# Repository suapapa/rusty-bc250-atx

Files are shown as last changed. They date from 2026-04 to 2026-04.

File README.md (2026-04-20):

# Rusty BC250 ATX

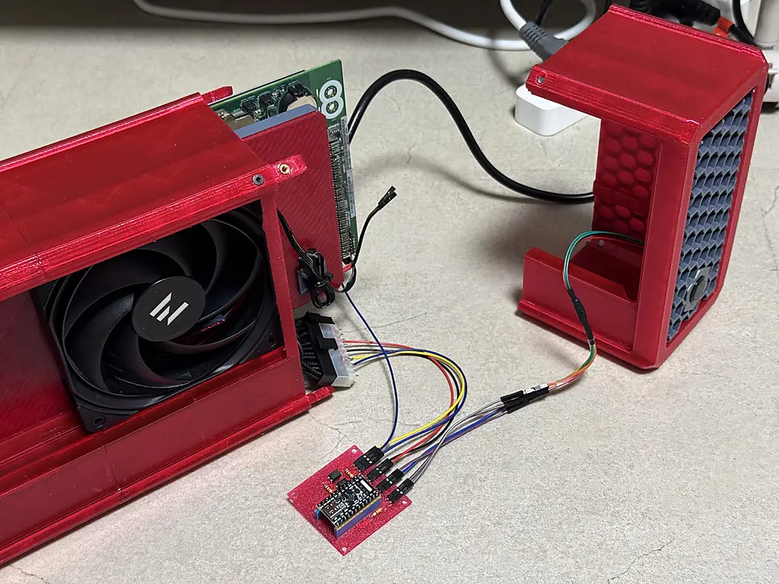
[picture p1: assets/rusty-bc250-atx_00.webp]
rusty-bc250-atx_00


- [In Action Video](https://www.youtube.com/watch?v=EkOmVfLqIu4)

ATX PSU soft-power adapter for the AMD BC250 mining board.
The BC250 lacks native ATX PS_ON circuitry; this firmware bridges that gap using a CH32V003 microcontroller.

## Features

| Function | Description |
|---|---|
| PS_ON control | Drive ATX PS_ON via optocoupler — active LOW at ATX connector, active HIGH at MCU |
| HOST_ON sense | Detect BC250 running state via optocoupler (12 V → 3.3 V isolated) |
| Power button | Debounced momentary button with short-press / long-press detection |
| Force off | 4-second hold → hard-cut ATX PS_ON regardless of HOST_ON state |
| LED output | Power status indicator (15 mA limited; J1 bypass up to 250 mA) |

## Board Assembly

The prototype PCB shown below was manufactured using a 3D printer.
- [sch/](sch/rusty-bc250-atx/) — KiCad schematic and PCB design
- [pcb_3dprint/](pcb_3dprint/) — STL and OpenSCAD files for 3D-printed PCB prototyping

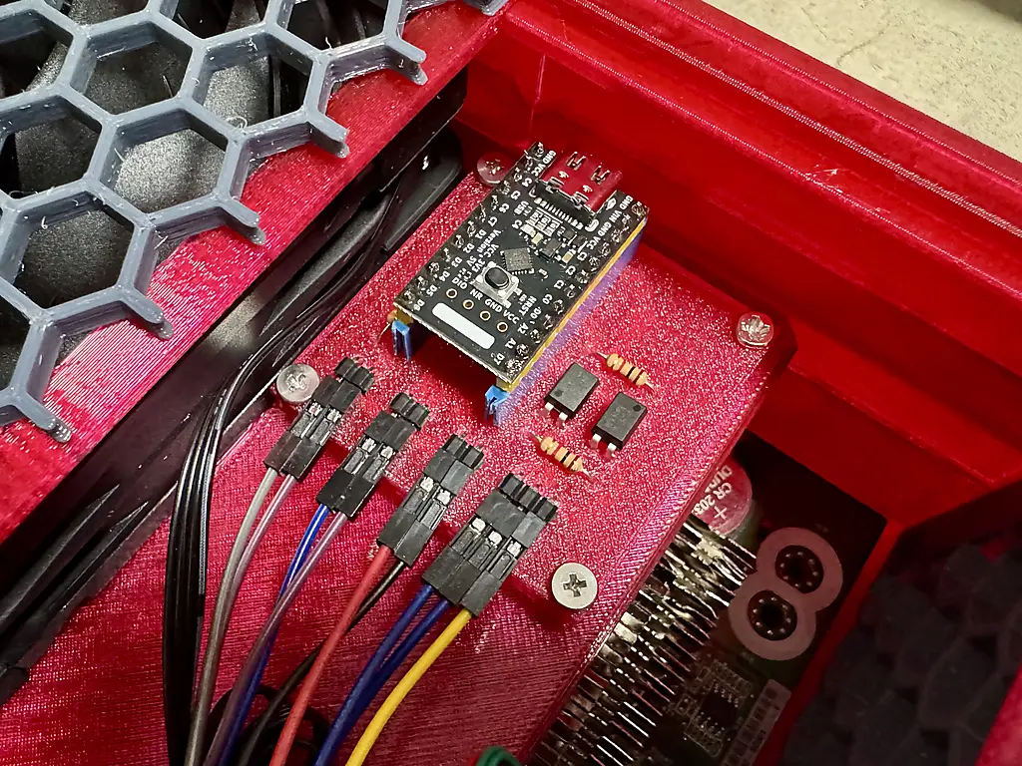
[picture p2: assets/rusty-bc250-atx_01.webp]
rusty-bc250-atx_01

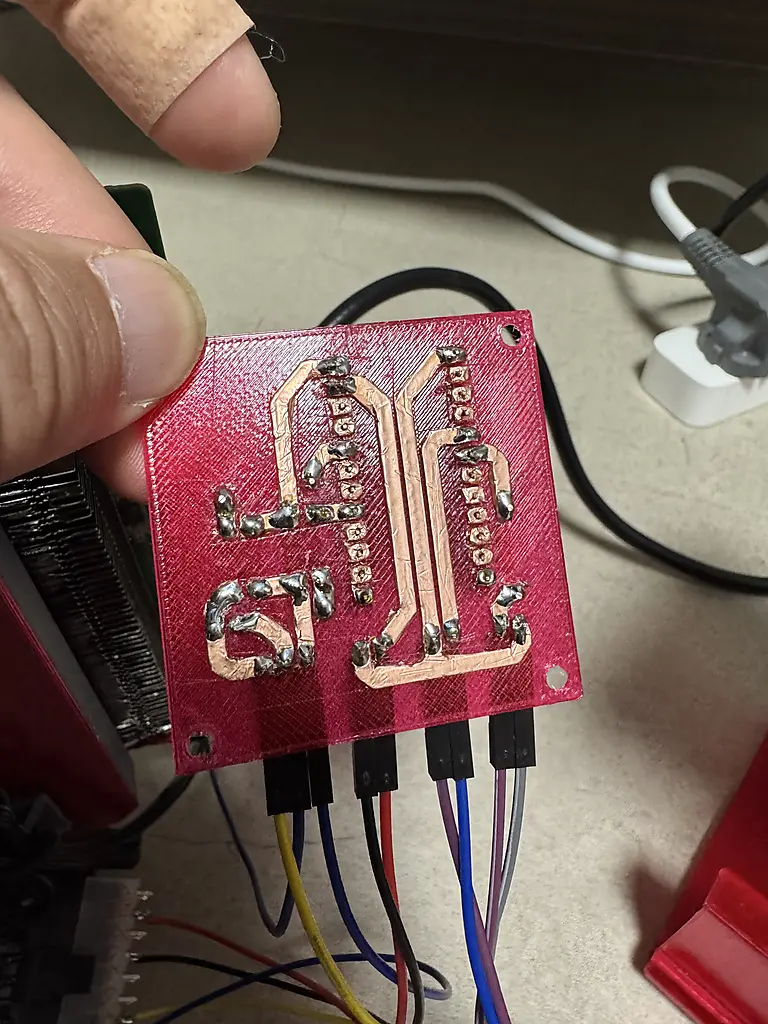
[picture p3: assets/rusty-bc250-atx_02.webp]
rusty-bc250-atx_02


## Power State Machine

```
IDLE
 └─ short press ──────────→ assert PS_ON ──→ POWERING_ON

POWERING_ON
 ├─ HOST_ON low ──────────→ RUNNING
 └─ timeout 5 s ──────────→ de-assert PS_ON ──→ IDLE   (PSU failed to start)

RUNNING
 ├─ hold 3 s ─────────────→ LED fast-blink warning
 ├─ hold 4 s ─────────────→ force de-assert PS_ON ──→ IDLE
 └─ HOST_ON lost 500 ms ──→ de-assert PS_ON ──→ IDLE
```

## Hardware

- **MCU** — CH32V003F4U6 (RISC-V RV32EC, TSSOP-20)
- **Programmer** — WCH-LinkE via SWIO (PD1)
- See [PINMAP.md](PINMAP.md) for pin assignments
- See [CIRCUIT.md](CIRCUIT.md) for circuit diagrams
- See [BOM.md](BOM.md) for the full bill of materials

## Building

Rust nightly toolchain is required (`riscv32ec` target is not yet stable).
The correct toolchain is pinned via `rust-toolchain.toml`.

```bash
cargo build --release
```

## Flashing

Install [wlink](https://github.com/ch32-rs/wlink):

```bash
cargo install --git https://github.com/ch32-rs/wlink
```

Connect a WCH-LinkE probe to the board (SWIO → PD1, GND, 3.3 V), then:

```bash
cargo run --release
```

Serial debug output (SDI print) is enabled automatically and streamed by `wlink`.

## License

Licensed under the [MIT License](LICENSE-MIT).

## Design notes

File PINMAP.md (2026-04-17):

# Pin Map

| Signal | MCU Pin | Direction | Description |
|---|---|---|---|
| VIN | 5V_SB | PWR | ATX 5 V standby power input |
| GND | GND | PWR | Ground |
| PS_ON | PC3 | OUT | ATX PS_ON control via optocoupler (HIGH = PSU on) |
| HOST_ON_IN | PC0 | IN | BC250 running sense via CPU_FAN 2nd pin (12 V) |
| BTN_IN | PC6 | IN | Power button input, active-low (internal pull-up) |
| PWR_LED_OUT_P | PC7 | OUT | Power status LED anode (HIGH = on) |
| PWR_LED_OUT_N | GND | PWR | Power LED cathode (tied to GND) |

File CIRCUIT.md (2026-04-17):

# Circuit Description

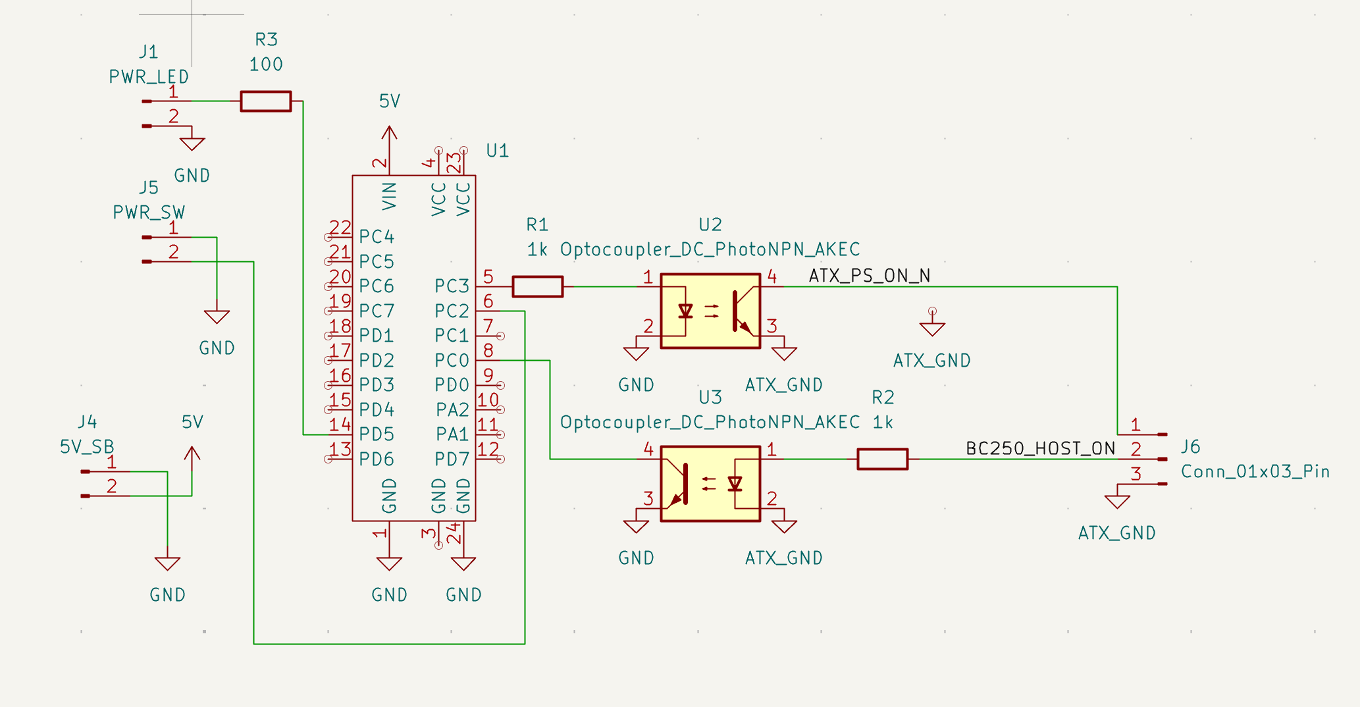
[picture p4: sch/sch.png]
sch


## PS_ON Control (PC3 → ATX PS_ON)

```
PC3 ──[R1 1kΩ]──→ U2 LED+
                   U2 LED- ──→ GND

U2 Collector ──→ ATX PS_ON (pin 16)
U2 Emitter   ──→ ATX GND   (pin 15)
```

PC3 HIGH → U2 on → ATX PS_ON pulled to GND → PSU starts.

---
## HOST_ON Sense (BC250 CPU_FAN Pin 2 → PC0 / HOST_ON_IN)

```
HOST_ON (CPU_FAN Pin 2, 12 V) ──[R2 1kΩ]──→ U3 LED+
```
                               U3 LED- ──→ GND

PC0 (internal pull-up) ──→ U3 Collector ──→ PC0 (HOST_ON_IN)
                            U3 Emitter   ──→ GND
```

BC250 ON (12 V) → U3 on → PC0 pulled LOW.  
BC250 OFF (0 V) → U3 off → internal pull-up → PC0 HIGH.

---

## Power Button Input (PC6 / BTN_IN)

```
PC6 (internal pull-up) ──┬── SW1 ──→ GND
```

Button pressed → PC6 LOW (active-low).

---

## Power LED (PC7 / PWR_LED_OUT_P)

```
PC7 ──[R3 100Ω]──[J1]──→ LED+ (PWR_LED_OUT_P)
                           LED- ──→ GND (PWR_LED_OUT_N)
```

R3 limits current to ~15 mA for standard backlit buttons.  
Short solder jumper J1 to bypass R3 for high-current loads (max 250 mA).
Note: Some schematic versions may show this on PC4, but PC7 is the designated pin for the external status LED.

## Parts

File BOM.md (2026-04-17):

# Bill of Materials — rusty-bc250-atx

| Ref | Description | Value / Part | Package | Qty |
|-----|---|---|---|-----|
| MOD1 | MCU module | WeActStudio CH32V003 CoreBoard | — | 1 |
| U2  | Optocoupler — PS_ON | PC817C | DIP-4 / SOP-4 | 1 |
| U3  | Optocoupler — HOST_ON | PC817C | DIP-4 / SOP-4 | 1 |
| R1  | PS_ON optocoupler LED current limit | 1 kΩ | 0402 | 1 |
| R2  | HOST_ON optocoupler LED current limit | 1 kΩ | 0402 | 1 |
| R3  | Power LED current limit (15 mA) | 100 Ω | 0402 | 1 |
| J1  | ATX connector (PS_ON + GND) | 2-pin header | 2.54 mm | 1 |
| J2  | Power LED connector | 2-pin header | 2.54 mm | 1 |
| J3  | HOST_ON input connector | 2-pin header | 2.54 mm | 1 |
| J4  | 5 V SB power input (ATX pin 9) | 2-pin header | 2.54 mm | 1 |

## Notes

- **MOD1** includes the CH32V003F4U6, 3.3 V LDO, decoupling caps, and a WCH-Link-compatible debug header — no discrete regulator or debug connector needed.
- Power the module from ATX 5 V SB via the module's VIN(5V) pin.
- **R3** limits PC4 GPIO current to ~15 mA for standard backlit buttons.
- **U2 / U3** can be any PC817 grade (A–D); grade C or better recommended for reliable switching at reduced drive currents.

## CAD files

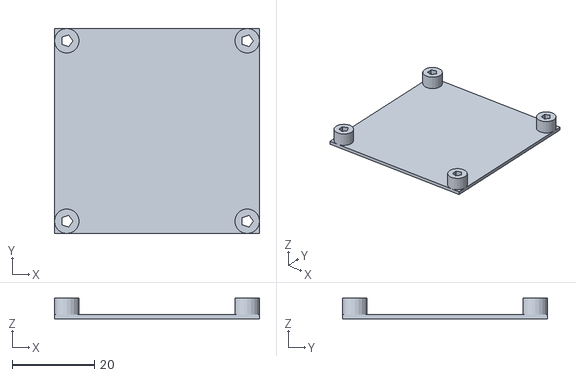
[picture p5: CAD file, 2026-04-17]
pcb_3dprint/support.stl
50.0 x 50.0 x 5.00

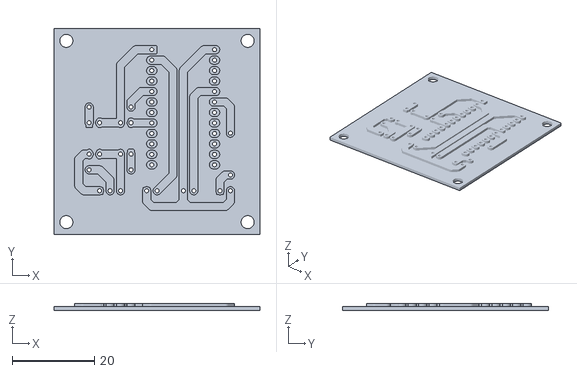
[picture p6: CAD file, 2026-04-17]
pcb_3dprint/pcb.stl
50.0 x 50.0 x 1.80

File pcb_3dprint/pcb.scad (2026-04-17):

difference() {
    union() {
        translate([-5,0,0]) cube([50,50,1]);
        linear_extrude(1.8) import("rusty-bc250-atx-F_Cu_route.svg");
    }
    translate([0,0,-0.5]) linear_extrude(3) import("rusty-bc250-atx-F_Cu_drill.svg");
    
    translate([-2,3,-3]) cylinder(h=6, r=1.6, $fn=20);
    translate([-2+44,3,-3]) cylinder(h=6, r=1.6, $fn=20);
    #translate([-2+44,0+47,-3]) cylinder(h=6, r=1.6, $fn=20);
    translate([-2,0+47,-3]) cylinder(h=6, r=1.6, $fn=20);
}

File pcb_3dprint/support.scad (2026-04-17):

difference() {
    /*
    union() {
        translate([-5,0,0]) cube([50,50,1]);
        linear_extrude(1.8) import("rusty-bc250-atx-F_Cu_route.svg");
    }
    translate([0,0,-0.5]) linear_extrude(3) import("rusty-bc250-atx-F_Cu_drill.svg");
    */
    

    difference() {    
        union() {
            translate([-5,0,0]) cube([50,50,1]);
            translate([-2,3,0]) cylinder(h=5, r=3, $fn=20);
            translate([-2+44,3,0]) cylinder(h=5, r=3, $fn=20);
            #translate([-2+44,0+47,0]) cylinder(h=5, r=3, $fn=20);
            translate([-2,0+47,0]) cylinder(h=5, r=3, $fn=20);
        }
        translate([-2,3,-3]) cylinder(h=16, r=1.6, $fn=20);
        translate([-2+44,3,-3]) cylinder(h=16, r=1.6, $fn=20);
        #translate([-2+44,0+47,-3]) cylinder(h=16, r=1.6, $fn=20);
        translate([-2,0+47,-3]) cylinder(h=16, r=1.6, $fn=20);
    }
}

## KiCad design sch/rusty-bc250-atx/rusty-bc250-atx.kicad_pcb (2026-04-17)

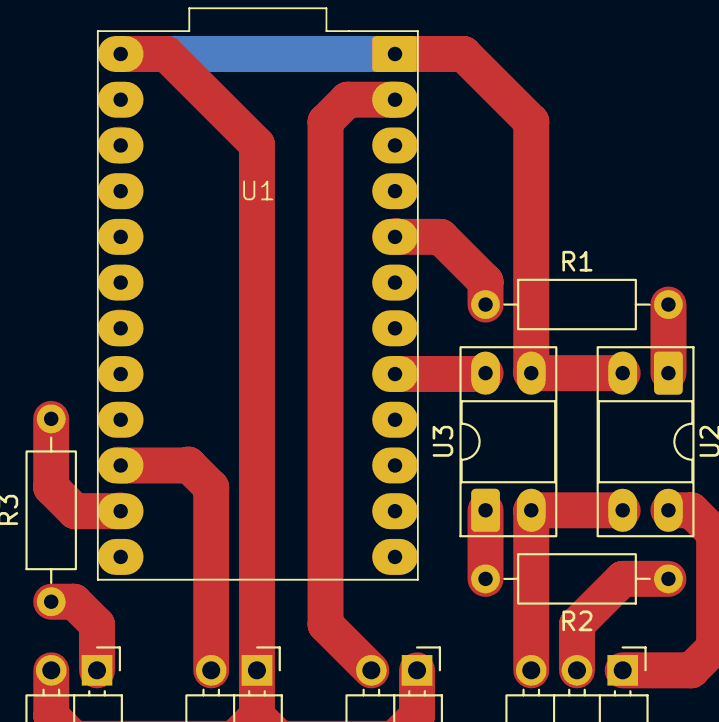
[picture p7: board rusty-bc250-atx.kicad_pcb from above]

Board: 2 copper layers, 10 parts (0 on the bottom side), 12 nets.

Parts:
J1: PWR_LED; PinHeader_1x02_P2.54mm_Horizontal
J4: 5V_SB; PinHeader_1x02_P2.54mm_Horizontal
J5: PWR_SW; PinHeader_1x02_P2.54mm_Horizontal
J6: Conn_01x03_Pin; PinHeader_1x03_P2.54mm_Horizontal
R1, R2: 1k; R_Axial_DIN0207_L6.3mm_D2.5mm_P10.16mm_Horizontal
R3: 100; R_Axial_DIN0207_L6.3mm_D2.5mm_P10.16mm_Horizontal
U1: CH32V003_CoreBoard_2
U2, U3: Optocoupler_DC_PhotoNPN_AKEC; DIP-4_W7.62mm_Socket_LongPads

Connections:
5V: J4.2, U1.2 (VIN)
/ATX_PS_ON_N: J6.1, U2.4
/BC250_HOST_ON: J6.2, R2.1
ATX_GND: J6.3, U2.3, U3.2
GND: J1.2, J4.1, J5.1, U1.1 (GND), U1.24 (GND), U2.2, U3.3
unnamed: J1.1, R3.1
unnamed: J5.2, U1.15 (PD4)
unnamed: R1.2, U2.1
unnamed: R2.2, U3.1
unnamed: R3.2, U1.14 (PD5)
unnamed: U1.8 (PC0), U3.4
unnamed: R1.1, U1.5 (PC3)

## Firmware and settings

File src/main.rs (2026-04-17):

#![no_std]
#![no_main]

use embassy_executor::Spawner;
use embassy_time::{Instant, Timer};
use ch32_hal::gpio::{Input, Level, Output, Pull};
use ch32_hal::println;
use panic_halt as _;

mod button;
mod led;
mod power;

use button::{ButtonEvent, ButtonState};
use led::{LedPattern, LedState};
use power::{PowerController, PowerState};

// ── Timing constants (milliseconds) ────────────────────────────────────────
const TICK_MS: u64 = 10;
const DEBOUNCE_MS: u64 = 20;
const FORCE_OFF_MS: u64 = 4000; // ATX spec — do not change
const WARN_BLINK_MS: u64 = 3000; // fast-blink warning starts this many ms before force-off
const PSOFF_TIMEOUT_MS: u64 = 10_000; // max wait for HOST_ON LOW after soft-off
const POWERON_TIMEOUT_MS: u64 = 5_000; // max wait for HOST_ON HIGH after PS_ON assert
const HOST_ON_GLITCH_MS: u64 = 500; // debounce unexpected HOST_ON drop while running

// Pre-computed tick counts derived from the constants above.
const DEBOUNCE_TICKS: u32 = (DEBOUNCE_MS / TICK_MS) as u32;
const WARN_TICKS: u32 = (WARN_BLINK_MS / TICK_MS) as u32;
const FORCE_TICKS: u32 = (FORCE_OFF_MS / TICK_MS) as u32;

#[embassy_executor::main(entry = "ch32_hal::entry")]
async fn main(_spawner: Spawner) -> ! {
    ch32_hal::debug::SDIPrint::enable();
    let p = ch32_hal::init(ch32_hal::Config::default());

    // ── Outputs ──────────────────────────────────────────────────────────────
    // PC3: PS_ON — MCU HIGH = optocoupler on = ATX PS_ON pulled LOW = PSU starts.
    let mut ps_on = Output::new(p.PC3, Level::Low, Default::default());
    // PC4: Built-in LED — HIGH = on. On by default; turns off while BTN_IN is held.
    let mut builtin_led = Output::new(p.PC4, Level::High, Default::default());
    // PC7: PWR_LED_OUT_P — HIGH = LED on.
    let mut led_pin = Output::new(p.PC7, Level::Low, Default::default());

    // ── Inputs ───────────────────────────────────────────────────────────────
    // PC0: HOST_ON_IN — LOW = BC250 is running (optocoupler inverts).
    let host_on_pin = Input::new(p.PC0, Pull::Up);
    // PC6: BTN_IN — LOW = pressed (active-low with internal pull-up).
    let btn_in_pin = Input::new(p.PC6, Pull::Up);

    // ── State ────────────────────────────────────────────────────────────────
    let mut btn = ButtonState::new();
    let mut led = LedState::new();
    let mut pwr = PowerController::new();

    println!("bc250-atx: started");

    let mut dbg_tick: u32 = 0;

    loop {
        Timer::after_millis(TICK_MS).await;

        // Read raw inputs.
        let pin_low = btn_in_pin.is_low(); // true = button pressed
        let host_on = host_on_pin.is_low(); // true = BC250 running (optocoupler inverts)

        // DEBUG: print pin_low for the first 20 ticks
        if dbg_tick < 20 {
            println!("dbg tick={} pin_low={}", dbg_tick, pin_low);
            dbg_tick += 1;
        }

        // Advance button state machine.
        let btn_event = btn.update(pin_low, DEBOUNCE_TICKS, WARN_TICKS, FORCE_TICKS);

        // ── Power state machine ───────────────────────────────────────────────
        match pwr.state {
            PowerState::Idle => {
                led.set(LedPattern::Off);
                if btn_event == ButtonEvent::ShortPress {
                    ps_on.set_high();
                    pwr.transition(PowerState::PoweringOn);
                    println!("IDLE -> POWERING_ON");
                }
            }

            PowerState::PoweringOn => {
                led.set(LedPattern::SlowBlink);
                if host_on {
                    pwr.transition(PowerState::Running);
                    println!("POWERING_ON -> RUNNING");
                } else if pwr.elapsed_ms() >= POWERON_TIMEOUT_MS {
                    ps_on.set_low();
                    pwr.transition(PowerState::Idle);
                    println!("POWERING_ON timeout -> IDLE");
                }
            }

            PowerState::Running => {
                // HOST_ON glitch filter: only de-assert PS_ON after HOST_ON has
                // been continuously LOW for HOST_ON_GLITCH_MS.
                if !host_on {
                    if pwr.host_on_lost_at.is_none() {
                        pwr.host_on_lost_at = Some(Instant::now());
                    } else {
                        let lost_ms = pwr
                            .host_on_lost_at
                            .unwrap() // safe: checked is_none above
                            .elapsed()
                            .as_millis();
                        if lost_ms >= HOST_ON_GLITCH_MS {
                            ps_on.set_low();
                            pwr.transition(PowerState::Idle);
                            println!("RUNNING HOST_ON lost -> IDLE");
                        }
                    }
                } else {
                    pwr.host_on_lost_at = None;
                }

                // LED: fast-blink while holding through warn window, solid otherwise.
                if btn.is_in_warn() {
                    led.set(LedPattern::FastBlink);
                } else {
                    led.set(LedPattern::On);
                }

                match btn_event {
                    ButtonEvent::LongPress => {
                        // Force off: immediately cut PS_ON.
                        ps_on.set_low();
                        pwr.transition(PowerState::Idle);
                        println!("RUNNING force off -> IDLE");
                    }
                    _ => {}
                }
            }

            PowerState::SoftOff => {
                led.set(LedPattern::SlowBlink);
                if !host_on {
                    ps_on.set_low();
                    pwr.transition(PowerState::Idle);
                    println!("SOFT_OFF HOST_ON low -> IDLE");
                } else if pwr.elapsed_ms() >= PSOFF_TIMEOUT_MS {
                    // BC250 did not shut down in time; force cut.
                    ps_on.set_low();
                    pwr.transition(PowerState::Idle);
                    println!("SOFT_OFF timeout -> IDLE");
                }
            }
        }

        // Apply LED pattern output.
        if led.update(TICK_MS as u32) {
            led_pin.set_high();
        } else {
            led_pin.set_low();
        }

        // Built-in LED: on by default; off while BTN_IN is stably held (debounced).
        if btn.is_pressed() {
            builtin_led.set_low();
        } else {
            builtin_led.set_high();
        }
    }
}

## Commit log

2026-04-17 rename project: ch32-bc250-atx -> rusty-bc250-atx
    [pcb.scad, rusty-bc250-atx.kicad_pcb, rusty-bc250-atx.kicad_sch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]
2026-04-17 docs: add webp assets, add stl exports and update README
    [pcb.stl, support.stl]
